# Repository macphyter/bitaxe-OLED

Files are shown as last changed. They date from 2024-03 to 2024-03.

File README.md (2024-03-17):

# bitaxe-OLED
bitaxe-OLED is a carrier board for a specific 1.9 inch 170x320 OLED
which is intended to connect to a bitaxe device via the BAP (Bitaxe Accessory Port)

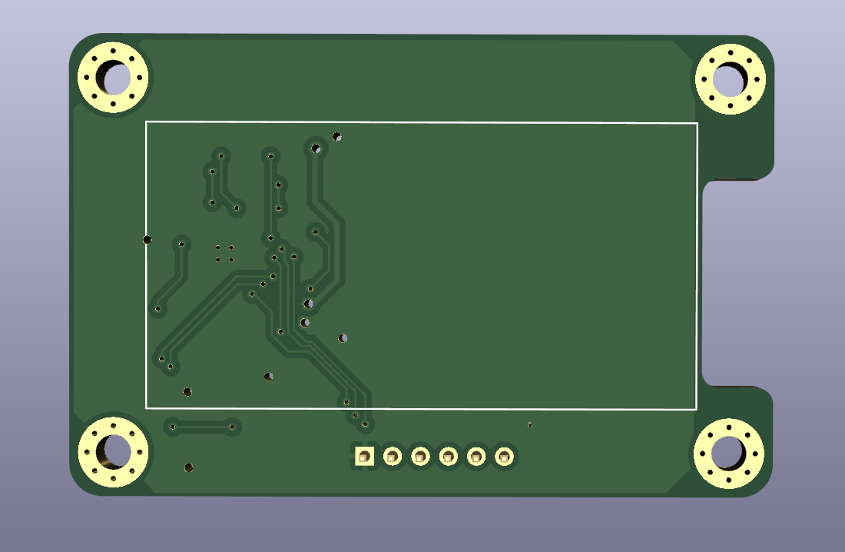
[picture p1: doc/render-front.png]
render-front


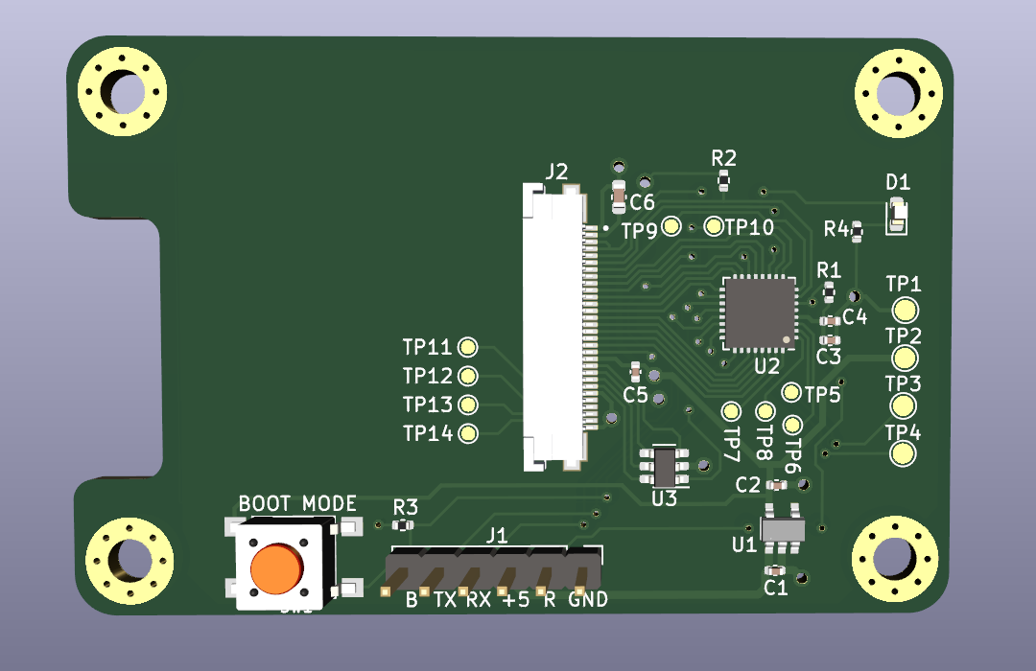
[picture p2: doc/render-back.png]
render-back


Here is the OLED display

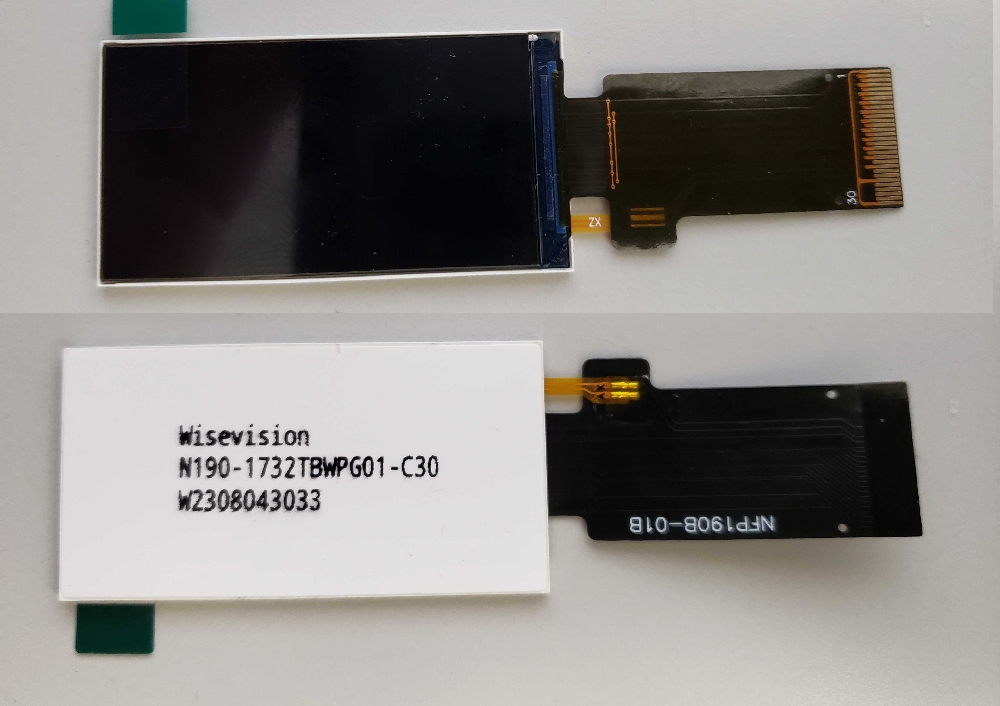
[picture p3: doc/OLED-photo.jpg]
OLED photo


The display attaches to the front of the carrier board using double sided foam tape, and 
the connector wraps around through the notch and attaches to the 30-pin connector on the back.

This OLED display uses a ST7789 controller and can operate in parallel mode or SPI mode
through its 30-pin connector.  The carrier board uses an STM32 MCU to drive the OLED 
and the hardware is designed to support either parallel or SPI mode, depending on the 
needs of the firmware developer.

The pins used to support each interface are described in this table

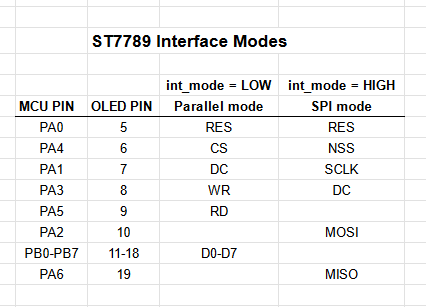
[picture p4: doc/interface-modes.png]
interface-modes


The MCU firmware is flashed using the built-in STM32 serial bootloader which is activated 
by holding down the "boot" button while powering on the board.  A standard FTDI cable 
pinout was used to make firmware flashing easy but this pinout is not identical to the 
Bitaxe BAP, so a custom cable solution may be necessary to connect this to a bitaxe.

The MCU firmware will display various GUI pages, and the data for these pages will be 
supplied by the bitaxe through the UART.

The MCU is an STM32G0B1KEU6 which has 512KB of flash memory and 144K of RAM, and runs at 
64 MHz from the internal oscillator.

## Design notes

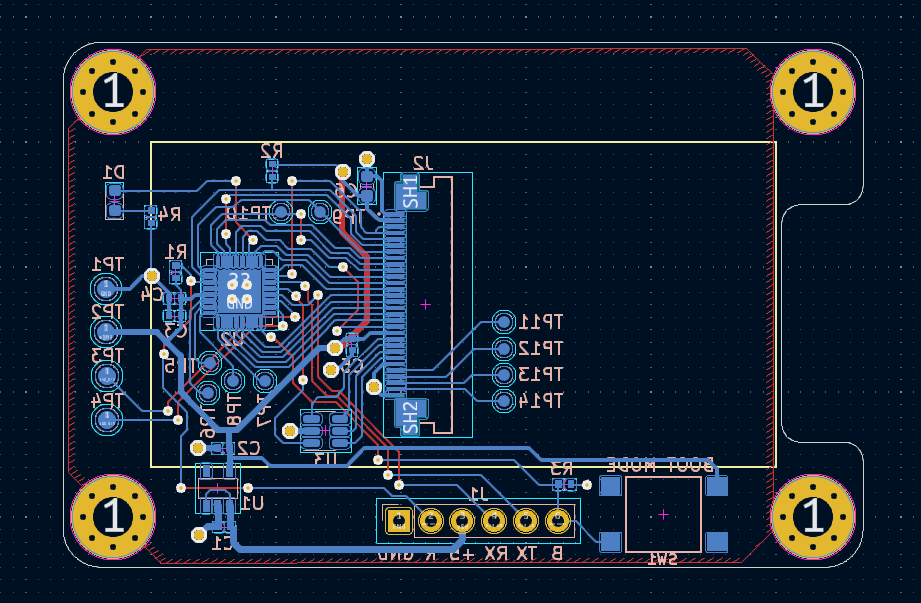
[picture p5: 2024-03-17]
doc/layout.png

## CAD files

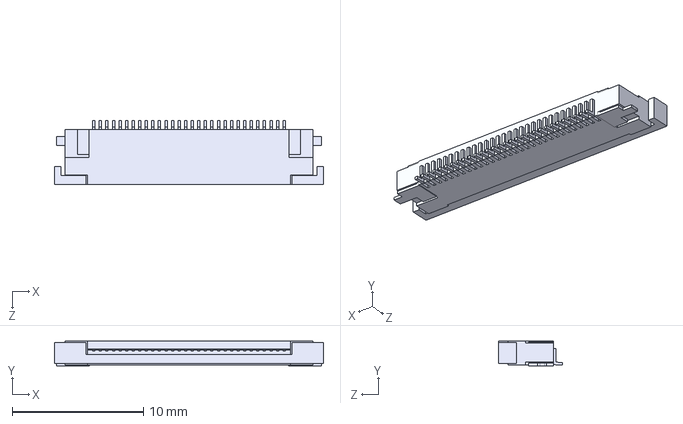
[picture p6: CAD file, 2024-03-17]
3d/SFV30R-4STE1HLF.step
20.5 x 1.87 x 4.90 mm

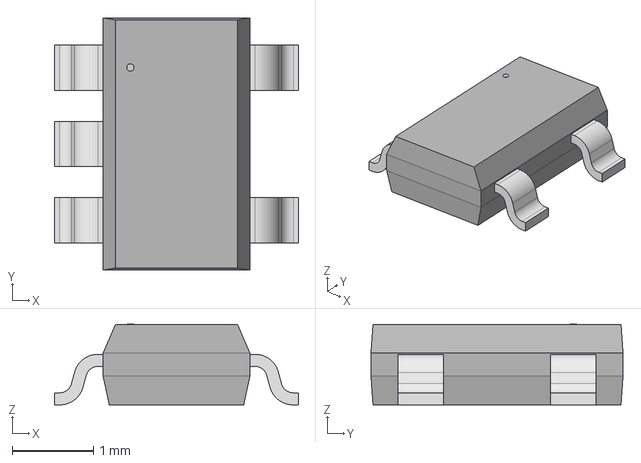
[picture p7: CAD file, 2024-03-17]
3d/TSOT-23-5_RIT.step
3.00 x 3.10 x 0.993 mm

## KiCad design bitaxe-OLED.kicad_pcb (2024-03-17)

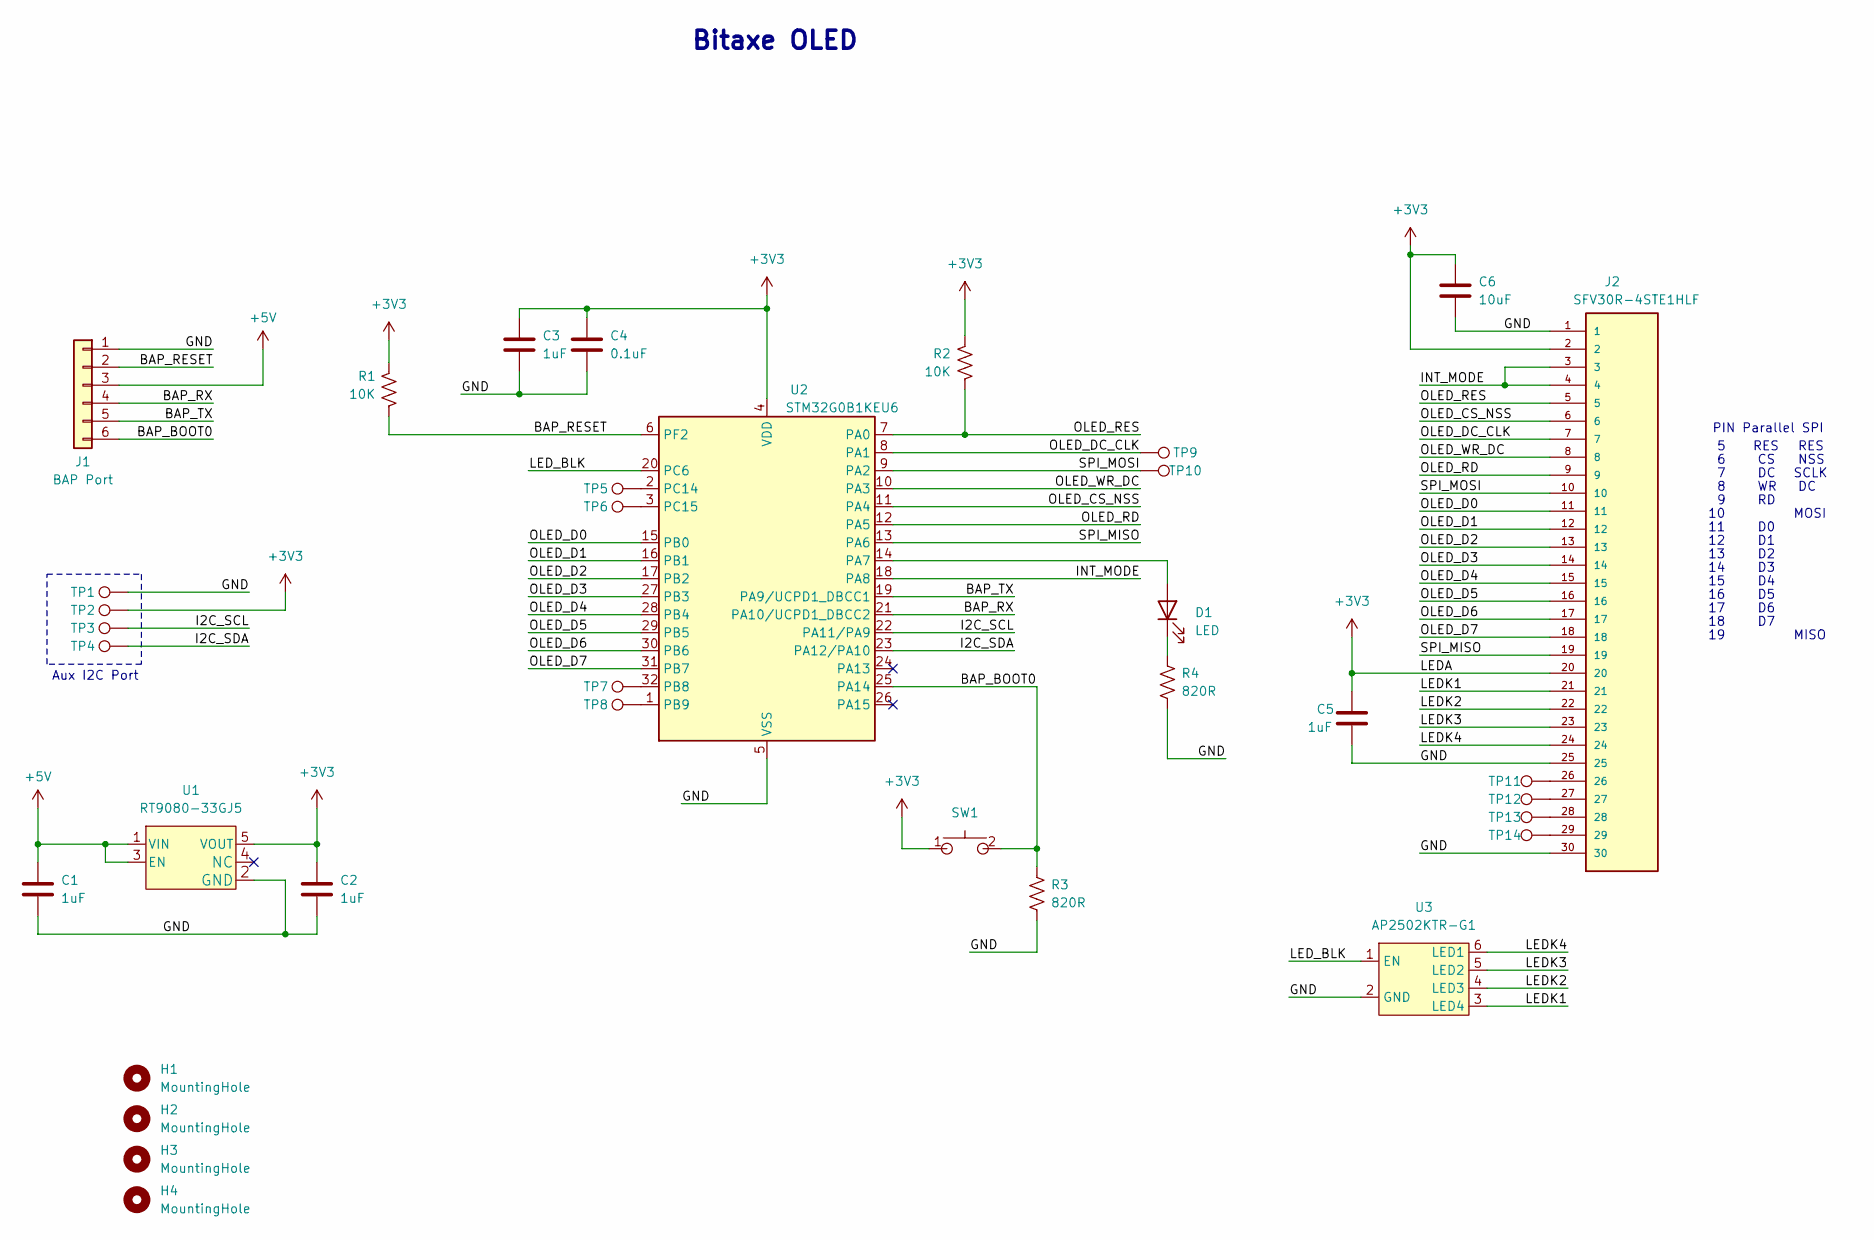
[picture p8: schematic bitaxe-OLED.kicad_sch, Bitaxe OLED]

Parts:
C1, C2, C3, C5: 1uF; C_0402_1005Metric
C4: 0.1uF; C_0402_1005Metric
C6: 10uF; C_0603_1608Metric
D1: LED; LED_0603_1608Metric
H1, H2, H3, H4: MountingHole; MountingHole_3.2mm_M3_Pad_Via
J1: BAP Port; PinHeader_1x06_P2.54mm_Vertical
J2: SFV30R-4STE1HLF; AMPHENOL_SFV30R-4STE1HLF; PARTNO SFV30R-4STE1HLF; JLCPCB KH-FG0.5-H2.0-30PIN
R1, R2: 10K; R_0402_1005Metric
R3, R4: 820R; R_0402_1005Metric
SW1: SWITCH-SPST; switch-TL3301; PARTNO EVQ-9P701P
TP1, TP2, TP3, TP4: TestPoint; TestPoint_Pad_D1.5mm
TP5, TP6, TP7, TP8, TP9, TP10, TP11, TP12, TP13, TP14: TestPoint; TestPoint_Pad_D1.0mm
U1: RT9080-33GJ5; PARTNO RT9080-33GJ5
U2: STM32G0B1KEU6; QFN-32-1EP_5x5mm_P0.5mm_EP3.45x3.45mm
U3: AP2502KTR-G1; SOT-23-6; PARTNO CLX6E-FKC-CH1M1D1BB7C3D3

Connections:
+3V3: C2.1, C3.1, C4.1, C5.1, C6.2, J2.2, J2.20, R1.1, R2.2, SW1.1, TP2.1, U1.5 (VOUT), U2.4 (VDD)
+5V: C1.1, J1.3, U1.1 (VIN), U1.3 (EN)
/BAP_BOOT0: J1.6, R3.2, SW1.2, U2.25 (PA14)
/BAP_RESET: J1.2, R1.2, U2.6 (PF2)
/BAP_RX: J1.4, U2.21 (PA10/UCPD1_DBCC2)
/BAP_TX: J1.5, U2.19 (PA9/UCPD1_DBCC1)
/GND: C1.2, C2.2, C3.2, C4.2, C5.2, C6.1, J1.1, J2.1, J2.25, J2.30, R3.1, R4.1, TP1.1, U1.2 (GND), U2.5 (VSS), U2.33 (VSS), U3.2 (GND)
/I2C_SCL: TP3.1, U2.22 (PA11/PA9)
/I2C_SDA: TP4.1, U2.23 (PA12/PA10)
/INT_MODE: J2.3, J2.4, U2.18 (PA8)
/LEDK1: J2.21, U3.3 (LED4)
/LEDK2: J2.22, U3.4 (LED3)
/LEDK3: J2.23, U3.5 (LED2)
/LEDK4: J2.24, U3.6 (LED1)
/LED_BLK: U2.20 (PC6), U3.1 (EN)
/OLED_CS_NSS: J2.6, U2.11 (PA4)
/OLED_D0: J2.11, U2.15 (PB0)
/OLED_D1: J2.12, U2.16 (PB1)
/OLED_D2: J2.13, U2.17 (PB2)
/OLED_D3: J2.14, U2.27 (PB3)
/OLED_D4: J2.15, U2.28 (PB4)
/OLED_D5: J2.16, U2.29 (PB5)
/OLED_D6: J2.17, U2.30 (PB6)
/OLED_D7: J2.18, U2.31 (PB7)
/OLED_DC_CLK: J2.7, TP9.1, U2.8 (PA1)
/OLED_RD: J2.9, U2.12 (PA5)
/OLED_RES: J2.5, R2.1, U2.7 (PA0)
/OLED_WR_DC: J2.8, U2.10 (PA3)
/SPI_MISO: J2.19, U2.13 (PA6)
/SPI_MOSI: J2.10, TP10.1, U2.9 (PA2)
unnamed: D1.2 (A), U2.14 (PA7)
unnamed: D1.1 (K), R4.2
unnamed: J2.26, TP11.1
unnamed: J2.27, TP12.1
unnamed: J2.28, TP13.1
unnamed: J2.29, TP14.1
unnamed: TP7.1, U2.32 (PB8)
unnamed: TP8.1, U2.1 (PB9)
unnamed: TP5.1, U2.2 (PC14)
unnamed: TP6.1, U2.3 (PC15)

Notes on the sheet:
SCLK
MOSI
RES
MISO
Aux I2C Port
PIN Parallel SPI
NSS
Bitaxe OLED

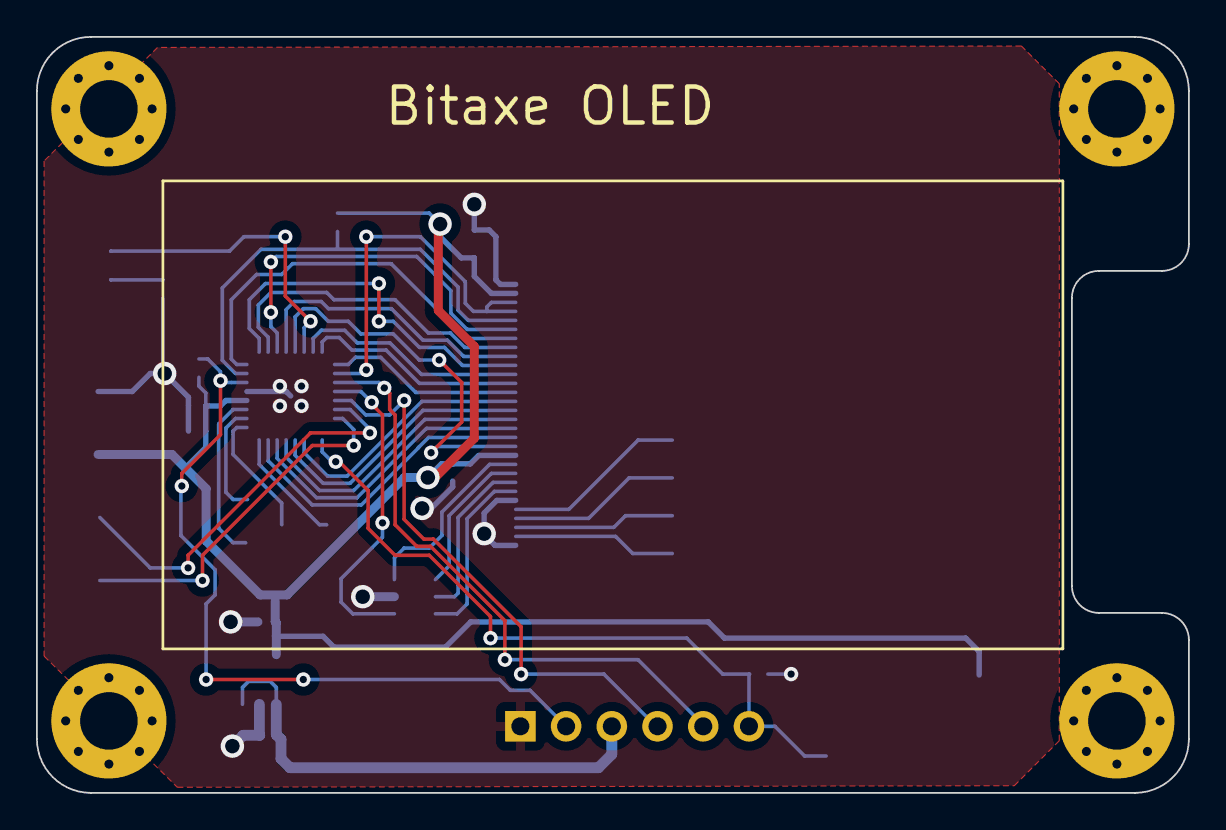
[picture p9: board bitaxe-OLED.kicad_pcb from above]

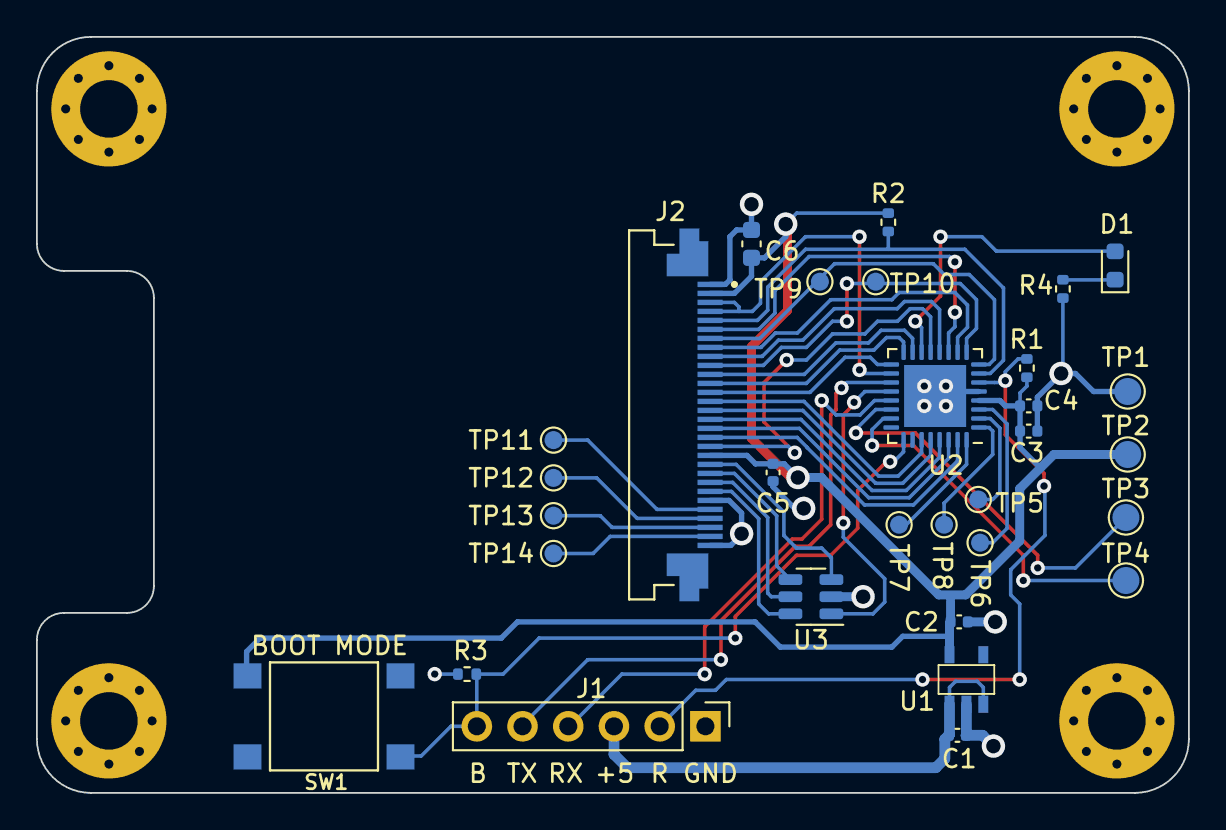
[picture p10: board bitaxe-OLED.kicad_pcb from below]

Board: 2 copper layers, 64.0 x 42.0 mm, 35 parts (31 on the bottom side), 40 nets.
